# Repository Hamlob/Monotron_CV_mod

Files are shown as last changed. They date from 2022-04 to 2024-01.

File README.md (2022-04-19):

# Monotron_CV_mod
A modification for Korg's Monotron Delay, which makes it accept standard Eurorack CV voltages (Pitch, Gate and Cutoff CV). The mod also provides an option to power the monotron via micro-USB.
<br />
<br />
Input specs:<br />
Pitch CV: 1V/oct (0-10V) <br />
Gate CV: GATE ON-> 5-12V <br />
Cutoff CV: 0-10Vpp (possibly more if you attenuate the signal using the Cutoff Trimmer, but it can damage the op-amp if the trimmer is in the wrong position).
<br />
<br />
Micro-usb: 5 +/- 10%

Output:<br />
Connect GATE, VCC, GND, CUTOFF and LFO testpads of Monotron to GATE, +5V, GND, CUTOFF and LFO pins of the mod PCB respectively, by soldering wires between them.<br />
GATE and CUTOFF are output signals being provided by the mod PCB. LFO is an input signal generated on the monotron board and routed into the mod PCB, which includes a proper output jack.
<br />
<br />
If you wish to use USB power, you need to cut the track as shown on Figure 1 to disconnect the batteries from Vcc. Then you need to solder a wire from the positive lead of the capacitor to the Bat pin of the mod PCB (Figure 2). This is done to prevent current flowing from USB to the batteries, potentionally damaging them (Figure 3).
<br />
<br />
Figure 1: <br />
ReadmeFigure1
<br />
<br />
Figure 2: <br />

<br />
Figure 3: <br />
ReadMeGithub

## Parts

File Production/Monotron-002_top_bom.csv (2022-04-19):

Comment | Designator | Footprint | LCSC Part #
1n | C1 | C0603
1u | C4 C8 | C0603
3k3 | R6 | R0603
6k8 | R10 | R0603
10k | R11 R21 | R0603
10n | C2 | C0603
10u | C5 | C0805
33k | R5 R9 | R0603
47k | R1 R2 R3 R4 R13 R14 R15 R16 R17 | R0603
47u | C9 C10 C11 C12 | C0805
68k | R18 R19 | R0603
100k | R7 | R0603
100n | C3 | C0603
220n | C6 C7 | C0603
LM324D | IC1 | SO14
MICRO-USB-RECEPTACLE47589-0001 | X1 | 47589-0001
N-MOSFET | Q1 | SOT23-3
TPB1 27 | TP1 | B1 27
TPB1 27 | TP2 | B1 27
TPB1 27 | TP3 | B1 27
TPB1 27 | TP4 | B1 27
TPB1 27 | TP5 | B1 27
TPB1 27 | TP6 | B1 27
TPB1 27 | TP7 | B1 27
TPB1 27 | TP8 | B1 27
TPB1 27 | TP9 | B1 27
TPS2105D | U1 | D8

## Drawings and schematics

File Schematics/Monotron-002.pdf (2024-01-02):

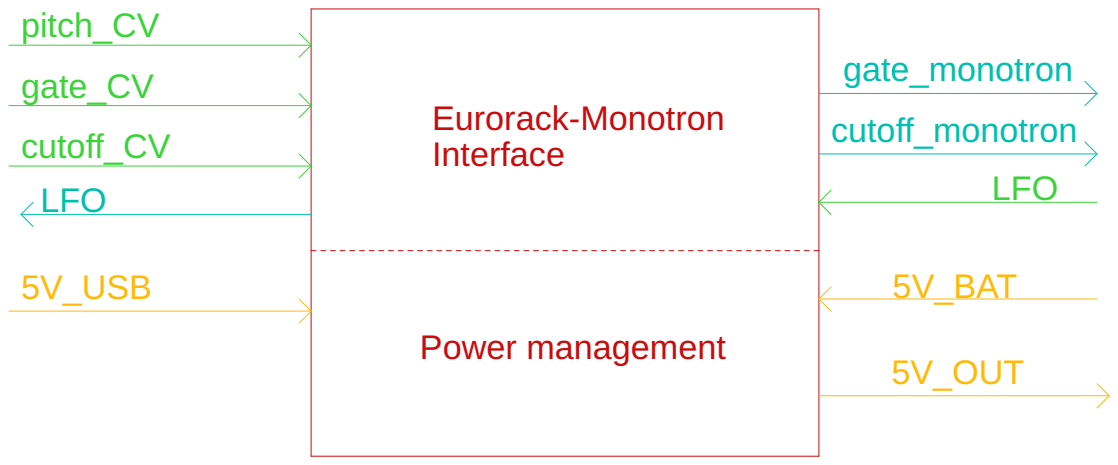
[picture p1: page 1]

WITHOUT PRIOR WRITTEN PERMISSION OF MAGE CONTROL SYSTEMS LTD. Title: Mage Control Systems Ltd. 45 Rankine Avenue East Kilbride F75 0QF

THIS DOCUMENT CONTAINS INFORMATION PROPRIETARY TO MAGE CONTROL SYSTEMS LTD. AND SHALL NOT BE REPRODUCED OR TRANSFERRED TO OTHER DOCUMENTS OR DISCLOSED

TO OTHER PARTIES OR USED FOR ANY PURPOSES OTHER THAT FOR WHICH IT IS FURNISHED

Name Peter Konecny | Initials PK | Date Drawn Chkd 13/04/2022

Interface between eurorack CV and Monotron

Document No: | Rev: CV_MONOTRON-002 2 | Sheet 1/3 of

Approved

02/01/2024 19:42 C:\Users\Admin\Documents\EAGLE\projects\Monotron\Monotron-002.sch (Sheet: 1/3)

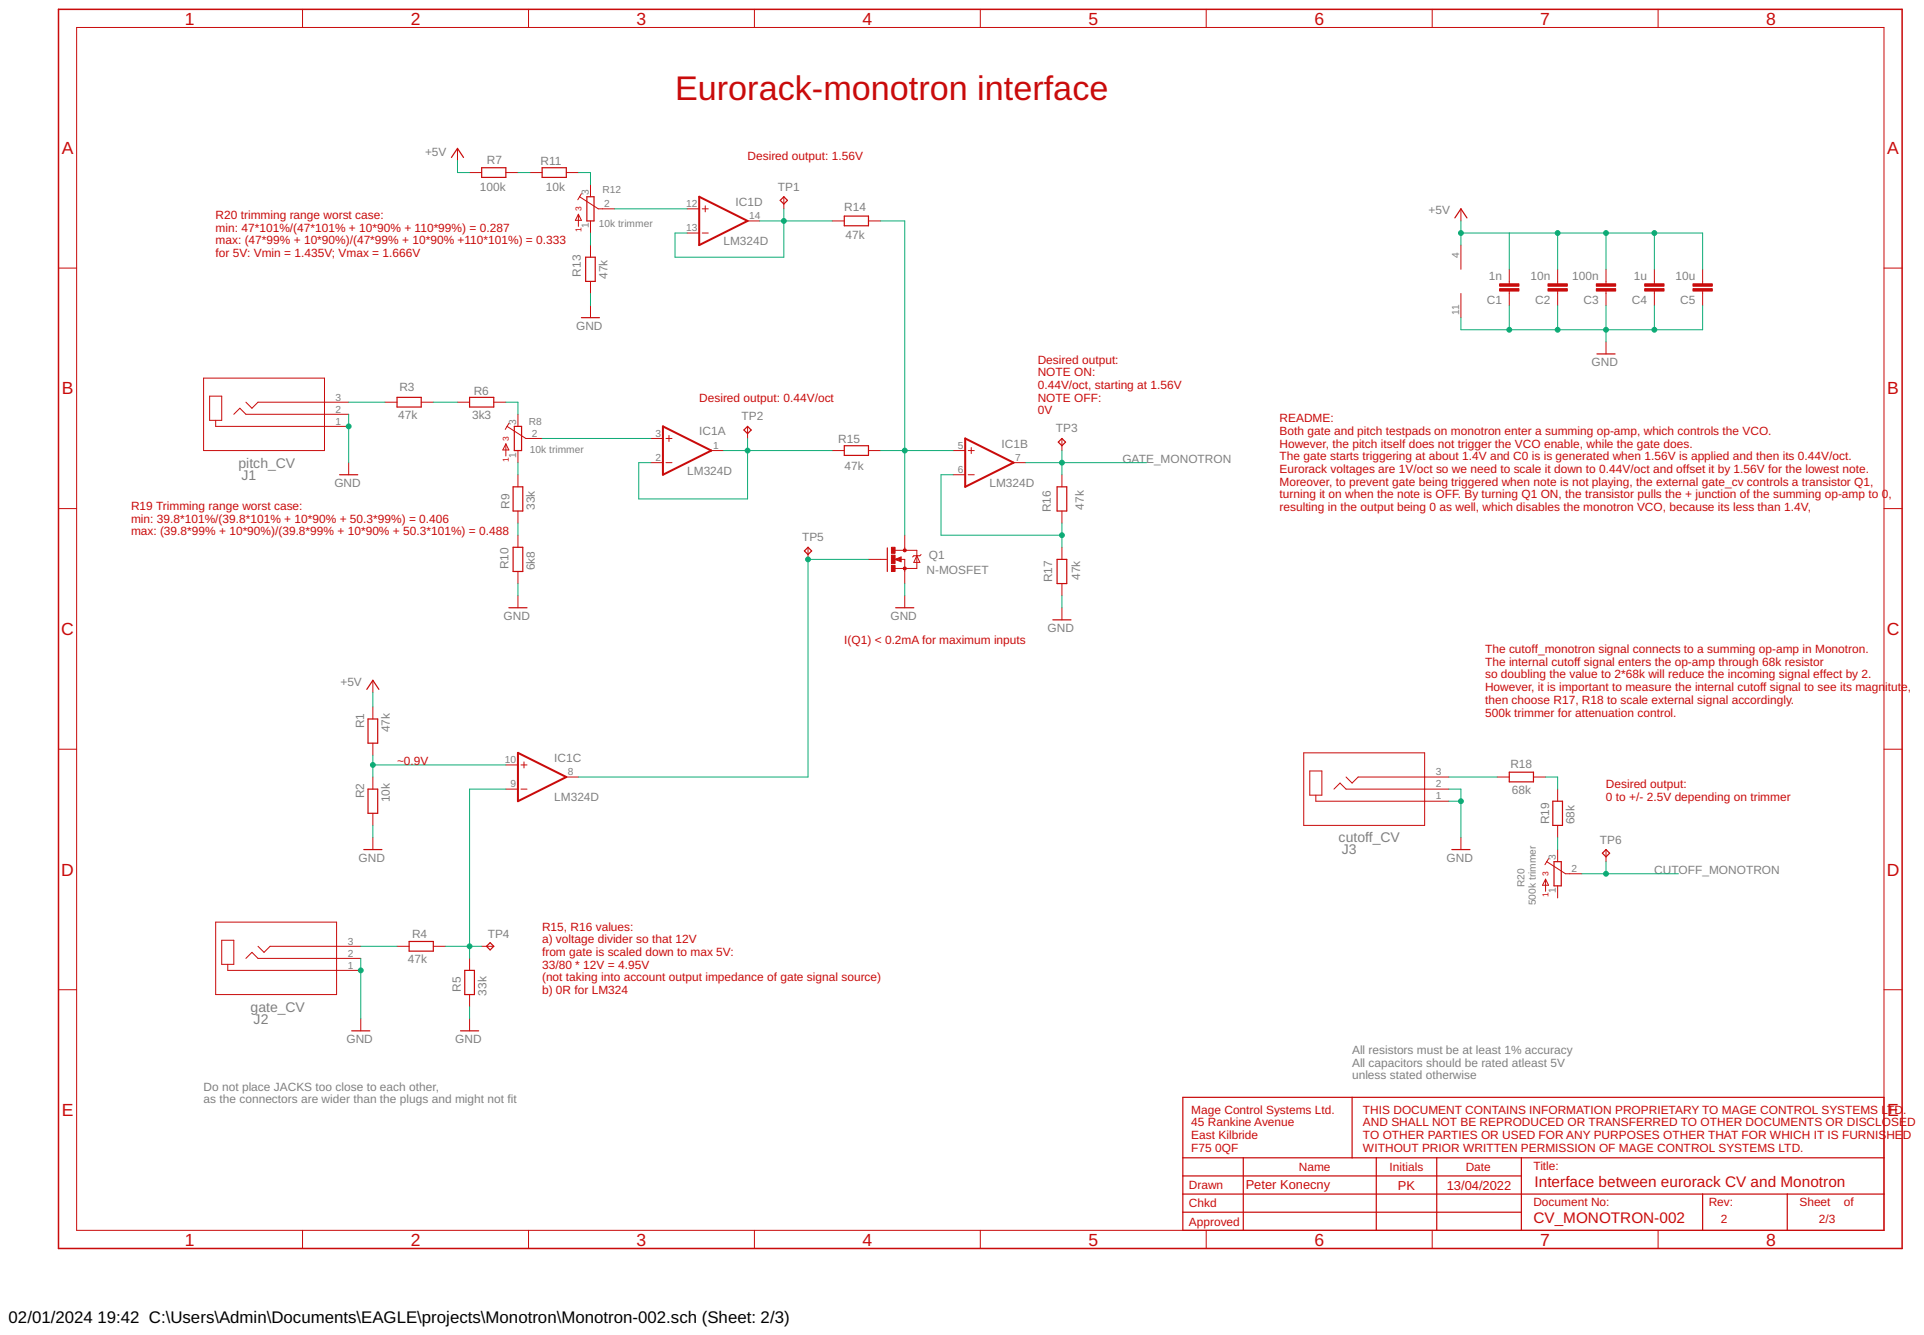
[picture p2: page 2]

R20 trimming range worst case: min: 47*101%/(47*101% + 10*90% + 110*99%) = 0.287 max: (47*99% + 10*90%)/(47*99% + 10*90% +110*101%) = 0.333

Desired output: NOTE ON: 0.44V/oct, starting at 1.56V

README: Both gate and pitch testpads on monotron enter a summing op-amp, which controls the VCO. However, the pitch itself does not trigger the VCO enable, while the gate does. The gate starts triggering at about 1.4V and C0 is is generated when 1.56V is applied and then its 0.44V/oct. Eurorack voltages are 1V/oct so we need to scale it down to 0.44V/oct and offset it by 1.56V for the lowest note. Moreover, to prevent gate being triggered when note is not playing, the external gate_cv controls a transistor Q1,

The cutoff_monotron signal connects to a summing op-amp in Monotron. The internal cutoff signal enters the op-amp through 68k resistor so doubling the value to 2*68k will reduce the incoming signal effect by 2. However, it is important to measure the internal cutoff signal to see its magnitute,

then choose R17, R18 to scale external signal accordingly. 500k trimmer for attenuation control.

Desired output: 0 to +/- 2.5V depending on trimmer

R15, R16 values: a) voltage divider so that 12V

from gate is scaled down to max 5V: 33/80 * 12V = 4.95V

(not taking into account output impedance of gate signal source)
b) 0R for LM324

All resistors must be at least 1% accuracy
All capacitors should be rated atleast 5V

unless stated otherwise Do not place JACKS too close to each other, as the connectors are wider than the plugs and might not fit

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

TO OTHER PARTIES OR USED FOR ANY PURPOSES OTHER THAT FOR WHICH IT IS FURNISHED

Name Peter Konecny | Initials PK | Date Drawn Chkd 13/04/2022

Interface between eurorack CV and Monotron

Document No: | Rev: CV_MONOTRON-002 2 | Sheet 2/3 of

Approved

02/01/2024 19:42 C:\Users\Admin\Documents\EAGLE\projects\Monotron\Monotron-002.sch (Sheet: 2/3)

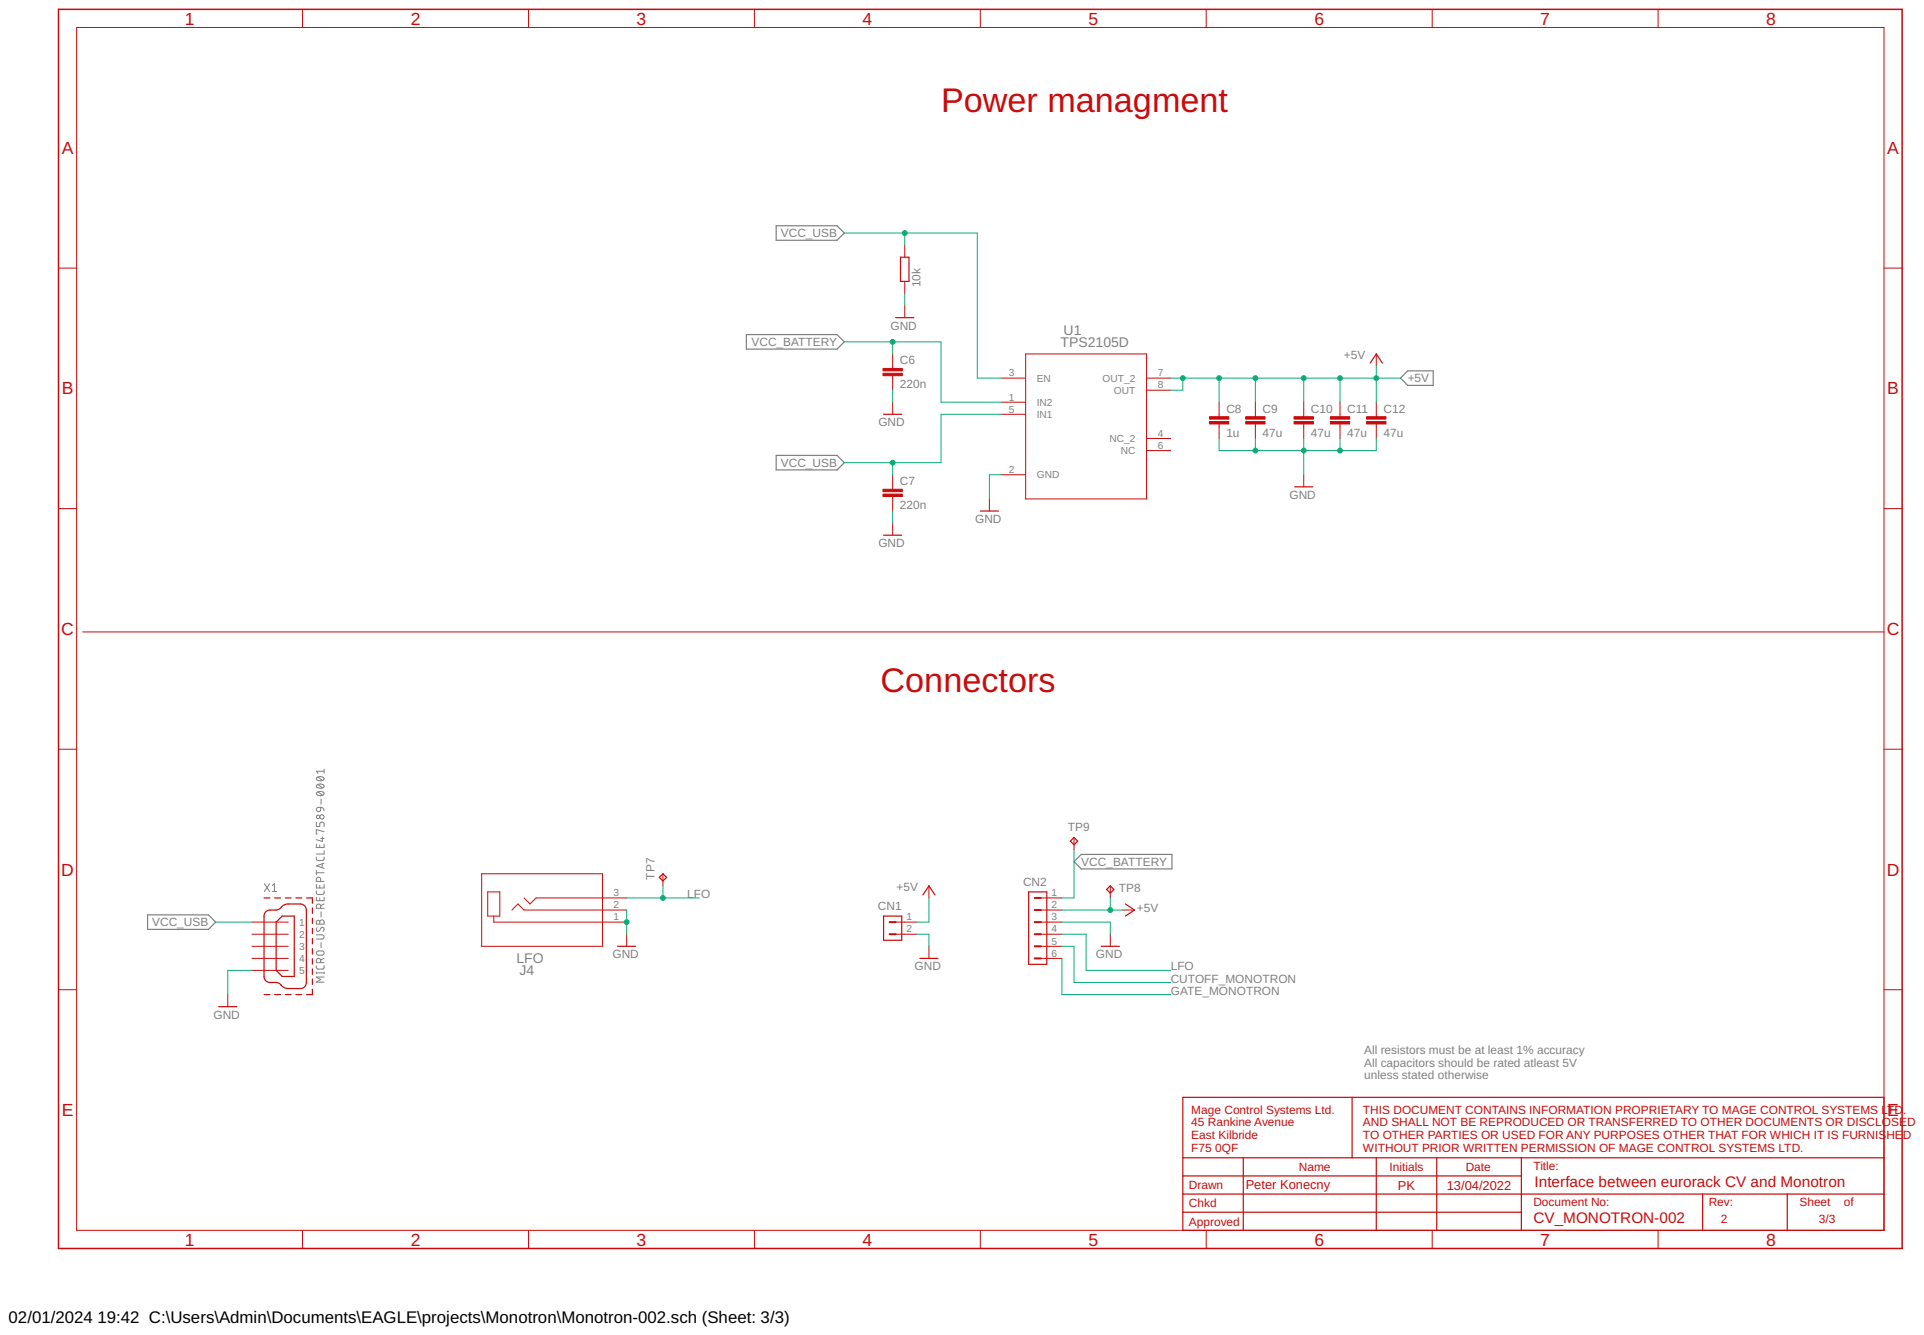
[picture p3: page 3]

All resistors must be at least 1% accuracy
All capacitors should be rated atleast 5V
unless stated otherwise

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

TO OTHER PARTIES OR USED FOR ANY PURPOSES OTHER THAT FOR WHICH IT IS FURNISHED

Name Peter Konecny | Initials PK | Date Drawn Chkd 13/04/2022

Interface between eurorack CV and Monotron

Document No: | Rev: CV_MONOTRON-002 2 | Sheet 3/3 of

Approved

02/01/2024 19:42 C:\Users\Admin\Documents\EAGLE\projects\Monotron\Monotron-002.sch (Sheet: 3/3)

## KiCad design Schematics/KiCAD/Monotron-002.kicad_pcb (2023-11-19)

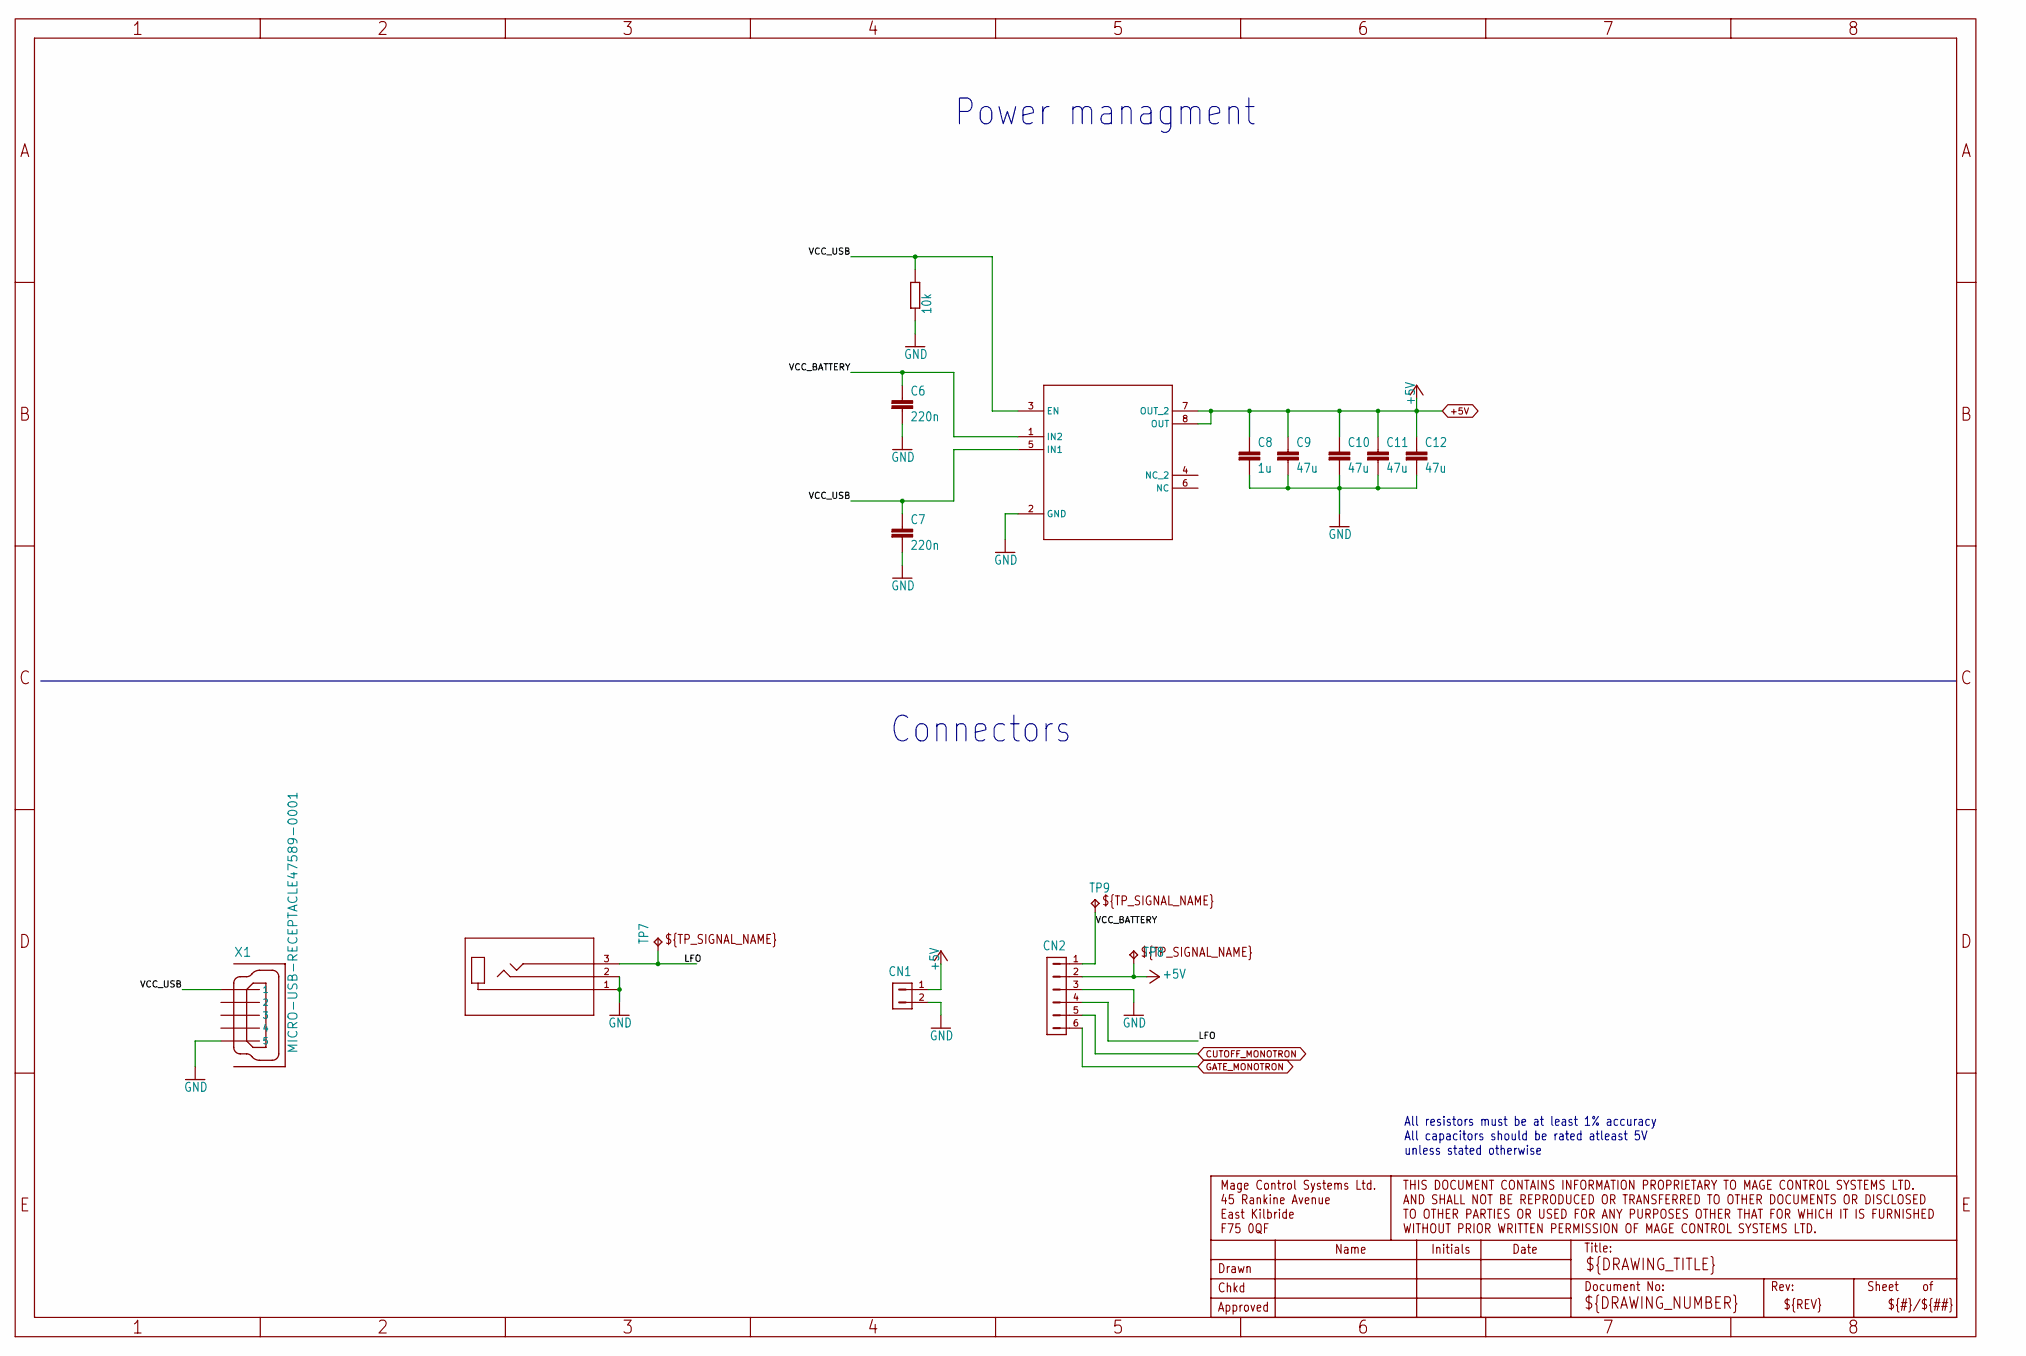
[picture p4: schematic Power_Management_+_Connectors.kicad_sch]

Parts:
C6, C7: 220n; C0603
C8: 1u; C0603
C9, C10, C11, C12: 47u; C0805
CN1: HDR-1X2-SIP-100; SIP-100-2V
CN2: HDR-1X6-SIP-100; SIP-100-6V
J4: STX-3000; STX-3000_KYC
R21: 10k; R0603
TP7, TP8, TP9: TPB1,27; B1,27
U1: TPS2105D; D8
X1: MICRO-USB-RECEPTACLE47589-0001; 47589-0001

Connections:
+5V: C8.1, C9.1, C10.1, C11.1, C12.1, CN1.1, CN2.2, TP8.TP, U1.7 (OUT_2), U1.8 (OUT); also elsewhere on the board
CUTOFF_MONOTRON: CN2.5; also elsewhere on the board
GATE_MONOTRON: CN2.6; also elsewhere on the board
GND: C6.2, C7.2, C8.2, C9.2, C10.2, C11.2, C12.2, CN1.2, CN2.3, J4.1, J4.2, R21.1, U1.2 (GND), X1.5; also elsewhere on the board
LFO: CN2.4, J4.3, TP7.TP
VCC_BATTERY: C6.1, CN2.1, TP9.TP, U1.1 (IN2)
VCC_USB: C7.1, R21.2, U1.3 (EN), U1.5 (IN1), X1.1

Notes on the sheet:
Power managment
Connectors
All resistors must be at least 1% accuracy All capacitors should be rated atleast 5V unless stated otherwise

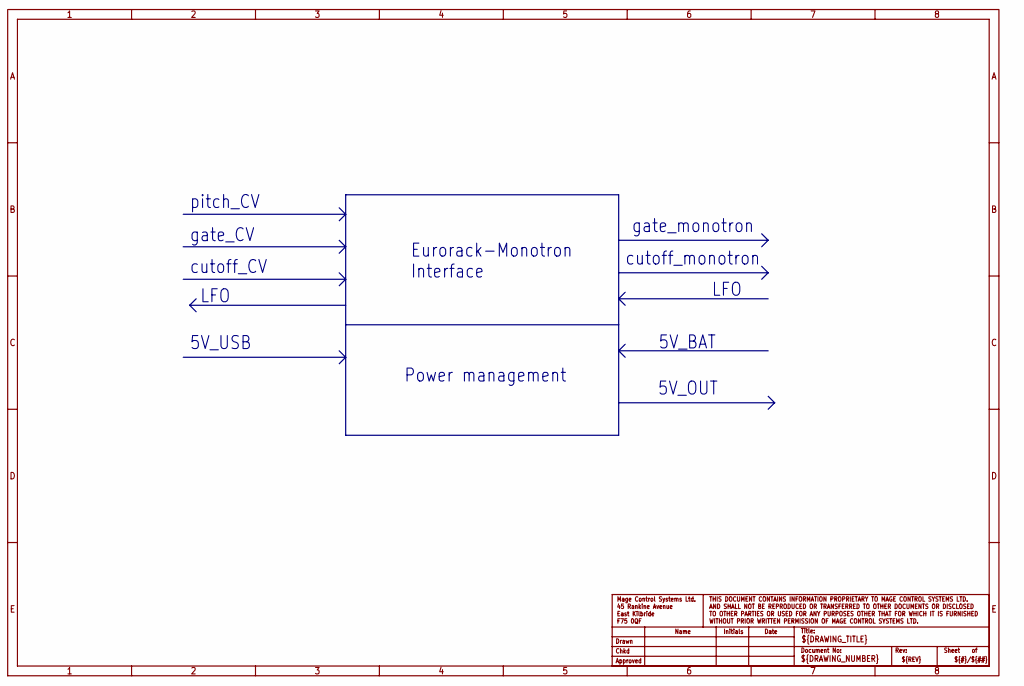
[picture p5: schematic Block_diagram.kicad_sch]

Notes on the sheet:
Power management
5V_USB
Eurorack-Monotron Interface
gate_CV
gate_monotron
LFO
pitch_CV
5V_OUT
cutoff_CV
cutoff_monotron
5V_BAT

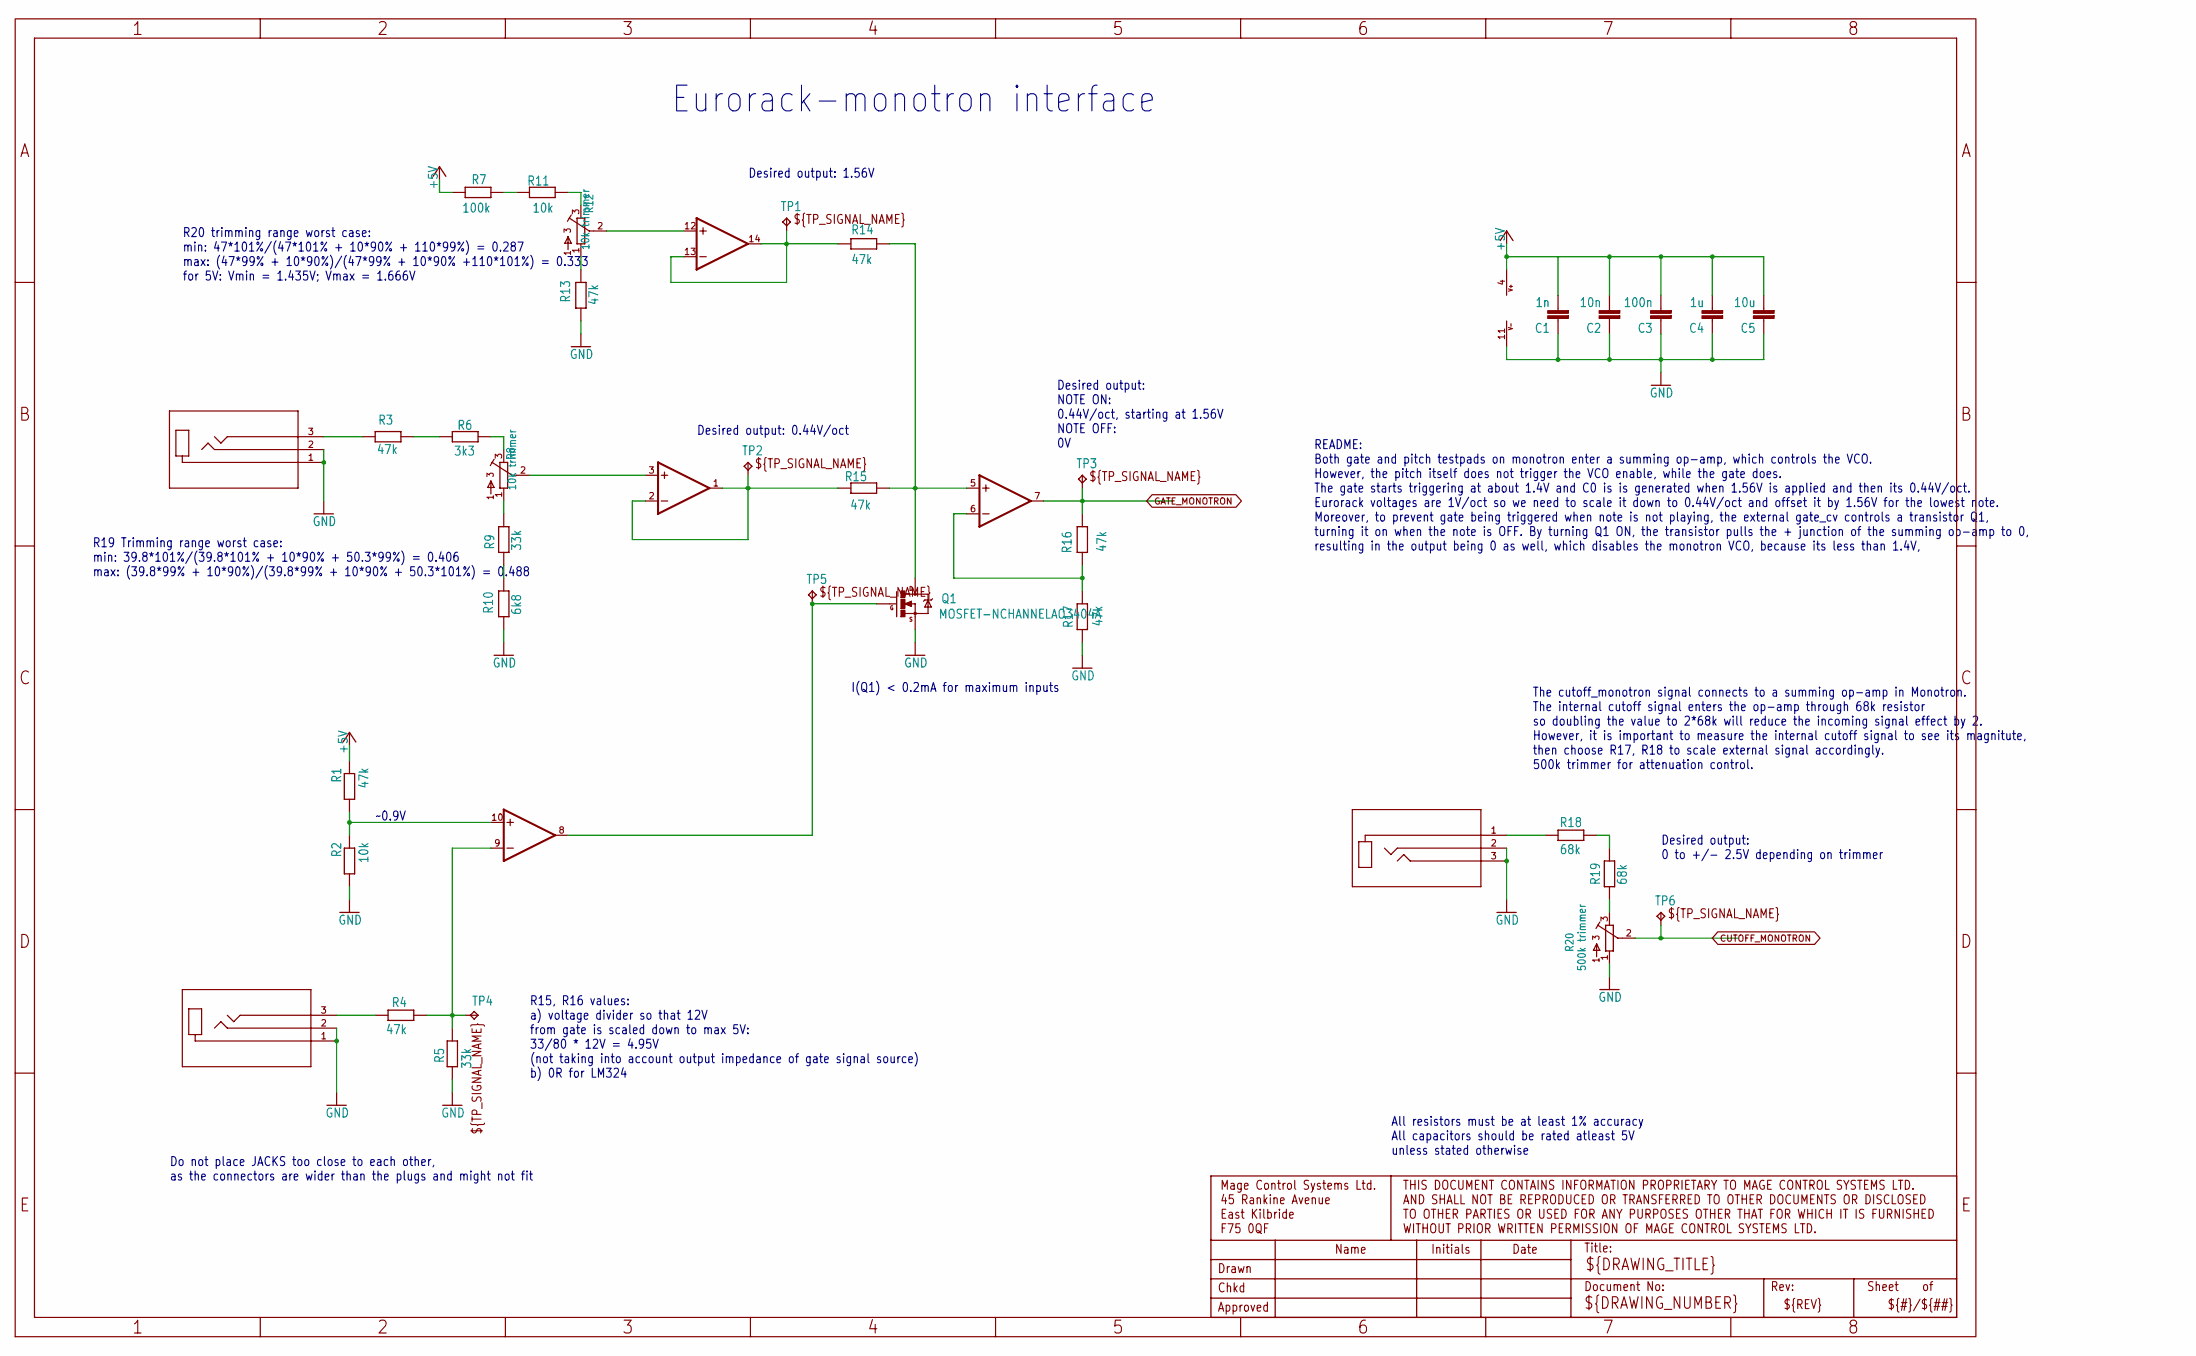
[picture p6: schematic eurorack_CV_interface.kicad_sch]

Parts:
C1: 1n; C0603
C2: 10n; C0603
C3: 100n; C0603
C4: 1u; C0603
C5: 10u; C0805
IC1: LM324D; SO14
J1, J2, J3: STX-3000; STX-3000_KYC
Q1: MOSFET-NCHANNELAO3404A; SOT23-3
R1, R3, R4, R13, R14, R15, R16, R17: 47k; R0603
R2, R11: 10k; R0603
R5, R9: 33k; R0603
R6: 3k3; R0603
R7: 100k; R0603
R8, R12: 10k trimmer; 3362R
R10: 6k8; R0603
R18, R19: 68k; R0603
R20: 500k trimmer; 3362R
TP1, TP2, TP3, TP4, TP5, TP6: TPB1,27; B1,27

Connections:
+5V: C1.2, C2.2, C3.2, C4.2, C5.2, IC1.4 (V+), R1.1, R7.2; also elsewhere on the board
CUTOFF_MONOTRON: R20.2, TP6.TP; also elsewhere on the board
GATE_MONOTRON: IC1.7 (OUT), R16.1, TP3.TP; also elsewhere on the board
GND: C1.1, C2.1, C3.1, C4.1, C5.1, IC1.11 (V-), J1.1, J1.2, J2.1, J2.2, J3.2, J3.3, Q1.2 (S), R2.2, R5.2, R10.1, R13.1, R17.2, R20.1; also elsewhere on the board
unnamed: R3.2, R6.2
unnamed: R9.1, R10.2
unnamed: IC1.1 (OUT), IC1.2 (-IN), R15.2, TP2.TP
unnamed: J1.3, R3.1
unnamed: IC1.5 (+IN), Q1.3 (D), R14.1, R15.1
unnamed: IC1.12 (+IN), R12.2
unnamed: J3.1, R18.2
unnamed: R18.1, R19.2
unnamed: R19.1, R20.3
unnamed: R8.1, R9.2
unnamed: IC1.8 (OUT), Q1.1 (G), TP5.TP
unnamed: R6.1, R8.3
unnamed: IC1.3 (+IN), R8.2
unnamed: R12.1, R13.2
unnamed: R11.1, R12.3
unnamed: R7.1, R11.2
unnamed: J2.3, R4.2
unnamed: IC1.9 (-IN), R4.1, R5.1, TP4.TP
unnamed: IC1.10 (+IN), R1.2, R2.1
unnamed: IC1.13 (-IN), IC1.14 (OUT), R14.2, TP1.TP
unnamed: IC1.6 (-IN), R16.2, R17.1

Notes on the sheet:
Desired output: 1.56V
R15, R16 values: a) voltage divider so that 12V from gate is scaled down to max 5V: 33/80 * 12V = 4.95V (not taking into account output impedance of gate signal source) b) 0R for LM324
All resistors must be at least 1% accuracy All capacitors should be rated atleast 5V unless stated otherwise
R20 trimming range worst case: min: 47*101%/(47*101% + 10*90% + 110*99%) = 0.287 max: (47*99% + 10*90%)/(47*99% + 10*90% +110*101%) = 0.333 for 5V: Vmin = 1.435V; Vmax = 1.666V
The cutoff_monotron signal connects to a summing op-amp in Monotron. The internal cutoff signal enters the op-amp through 68k resistor so doubling the value to 2*68k will reduce the incoming signal effect by 2. However, it is important to measure the internal cutoff signal to see its magnitute, the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
I(Q1) < 0.2mA for maximum inputs
README: Both gate and pitch testpads on monotron enter a summing op-amp, which controls the VCO. However, the pitch itself does not trigger the VCO enable, while the gate does. The gate starts triggering at about 1.4V and C0 is is generated when 1.56V is applied and then its 0.44V/oct. Eurorack vol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
Desired output: 0 to +/- 2.5V depending on trimmer
Desired output: 0.44V/oct
Eurorack-monotron interface
~0.9V
Do not place JACKS too close to each other, as the connectors are wider than the plugs and might not fit
Desired output: NOTE ON: 0.44V/oct, starting at 1.56V NOTE OFF: 0V
R19 Trimming range worst case: min: 39.8*101%/(39.8*101% + 10*90% + 50.3*99%) = 0.406 max: (39.8*99% + 10*90%)/(39.8*99% + 10*90% + 50.3*101%) = 0.488

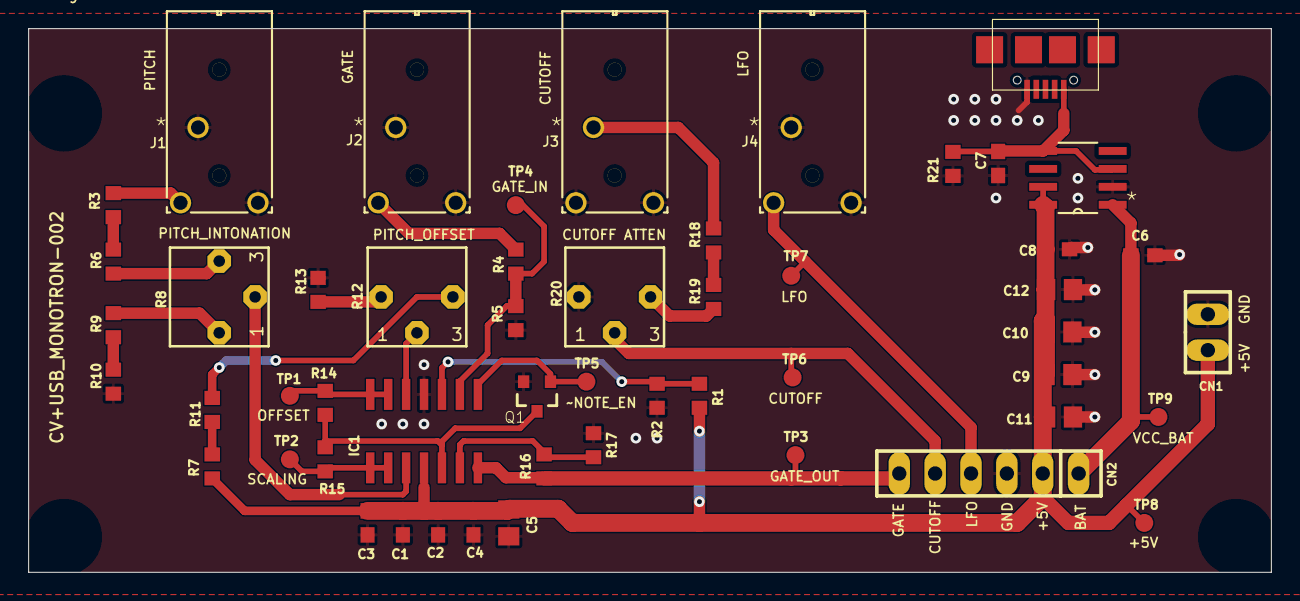
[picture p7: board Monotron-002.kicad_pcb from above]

Board: 2 copper layers, 88.0 x 38.5 mm, 52 parts (0 on the bottom side), 28 nets.

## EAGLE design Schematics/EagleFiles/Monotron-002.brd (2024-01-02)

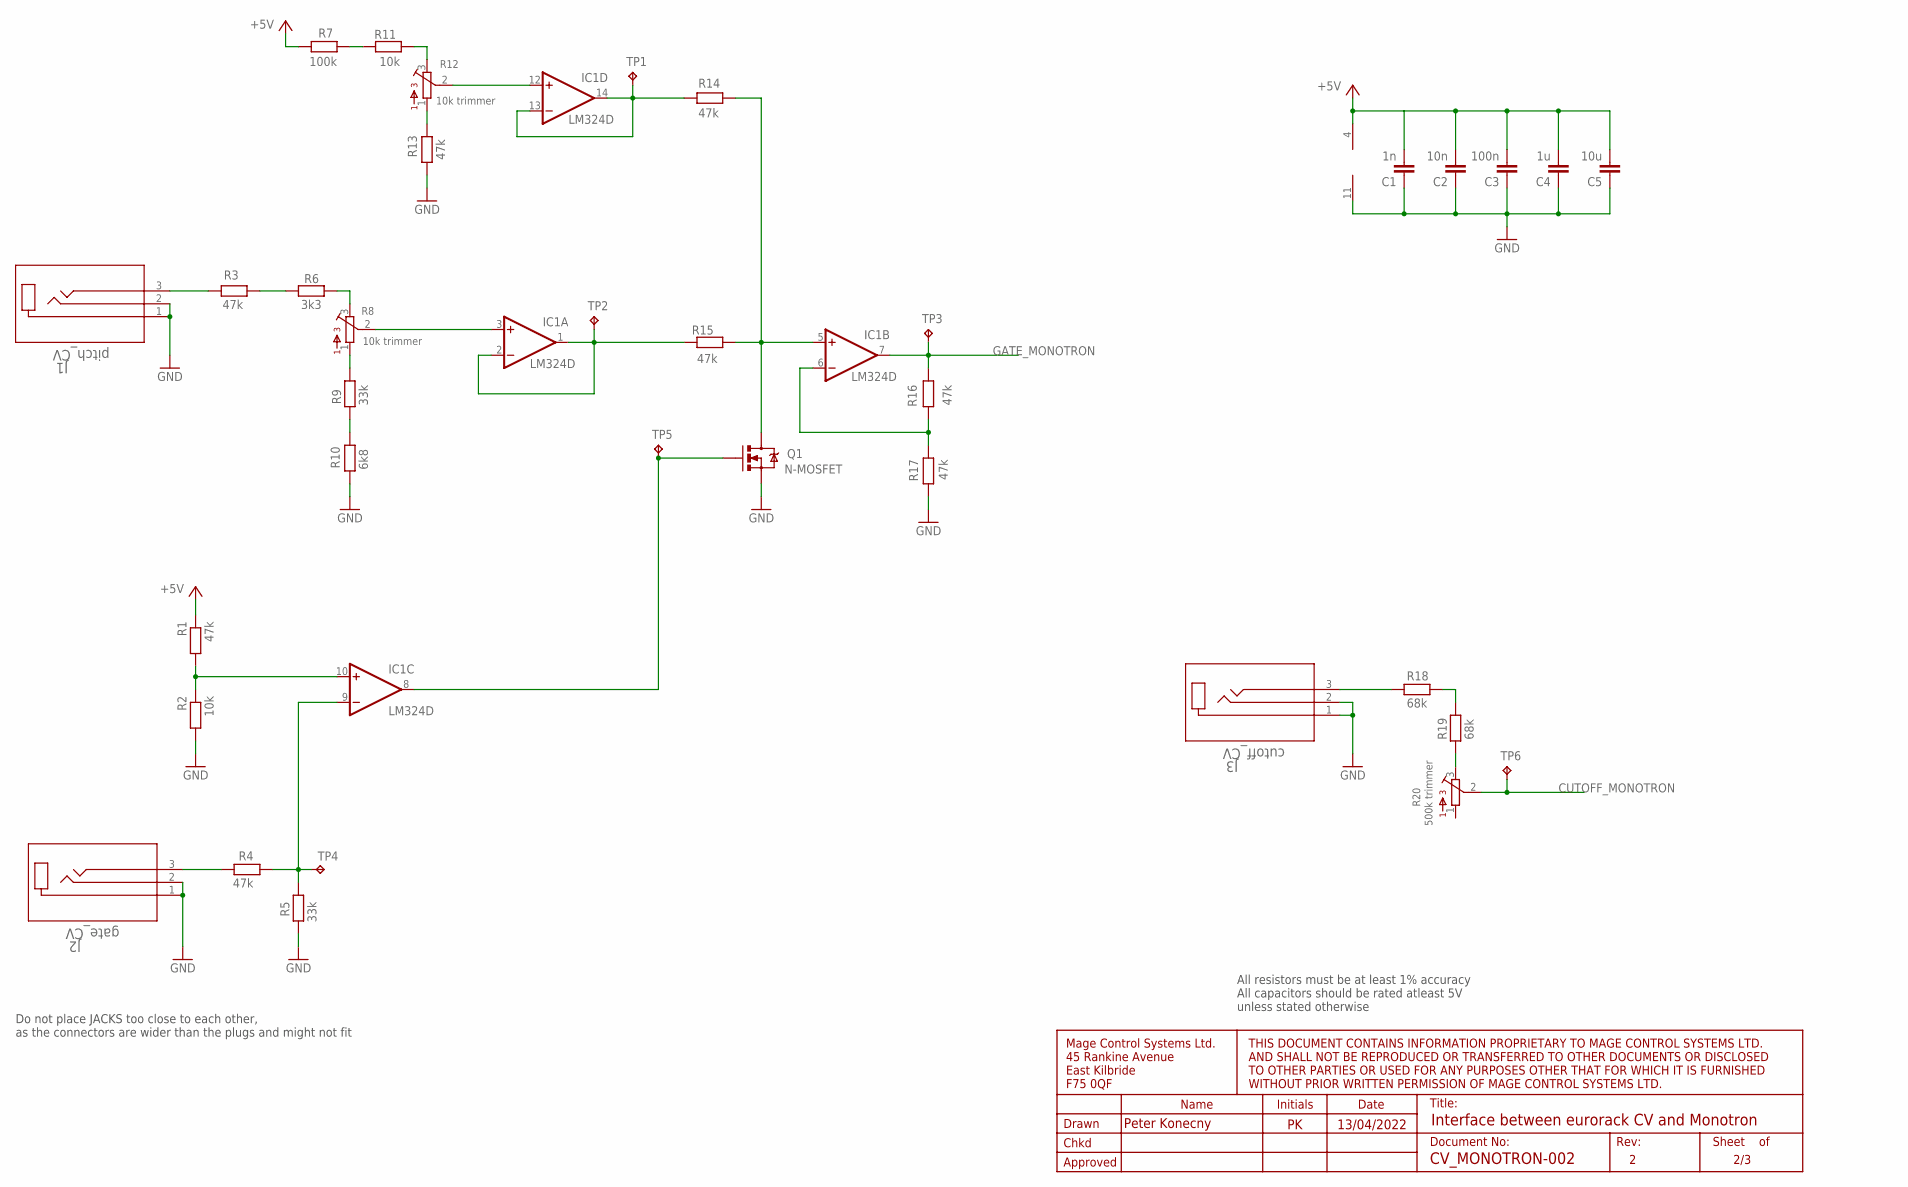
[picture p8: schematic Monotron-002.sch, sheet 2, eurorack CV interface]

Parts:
C1: 1n; C0603
C2: 10n; C0603
C3: 100n; C0603
C4: 1u; C0603
C5: 10u; C0805
IC1: LM324D; SO14
J1: pitch_CV; STX-3000_KYC
J2: gate_CV; STX-3000_KYC
J3: cutoff_CV; STX-3000_KYC
Q1: N-MOSFET; SOT23-3
R1, R3, R4, R13, R14, R15, R16, R17: 47k; R0603
R2, R11: 10k; R0603
R5, R9: 33k; R0603
R6: 3k3; R0603
R7: 100k; R0603
R8, R12: 10k trimmer; 3362R
R10: 6k8; R0603
R18, R19: 68k; R0603
R20: 500k trimmer; 3362R
TP1, TP2, TP3, TP4, TP5, TP6: TPB1,27; B1,27

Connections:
+5V: C1.2, C2.2, C3.2, C4.2, C5.2, IC1.4 (V+), R1.1, R7.2; also elsewhere on the board
CUTOFF_MONOTRON: R20.2, TP6.TP; also elsewhere on the board
GATE_MONOTRON: IC1.7 (OUT), R16.1, TP3.TP; also elsewhere on the board
GND: C1.1, C2.1, C3.1, C4.1, C5.1, IC1.11 (V-), J1.1, J1.2, J2.1, J2.2, J3.1, J3.2, Q1.2 (S), R2.2, R5.2, R10.1, R13.1, R17.2; also elsewhere on the board
unnamed: R3.2, R6.2
unnamed: R9.1, R10.2
unnamed: IC1.1 (OUT), IC1.2 (-IN), R15.2, TP2.TP
unnamed: J1.3, R3.1
unnamed: IC1.5 (+IN), Q1.3 (D), R14.1, R15.1
unnamed: J3.3, R18.2
unnamed: IC1.12 (+IN), R12.2
unnamed: R18.1, R19.2
unnamed: R19.1, R20.3
unnamed: R8.1, R9.2
unnamed: IC1.8 (OUT), Q1.1 (G), TP5.TP
unnamed: R6.1, R8.3
unnamed: IC1.3 (+IN), R8.2
unnamed: R12.1, R13.2
unnamed: R11.1, R12.3
unnamed: R7.1, R11.2
unnamed: J2.3, R4.2
unnamed: IC1.9 (-IN), R4.1, R5.1, TP4.TP
unnamed: IC1.10 (+IN), R1.2, R2.1
unnamed: IC1.13 (-IN), IC1.14 (OUT), R14.2, TP1.TP
unnamed: IC1.6 (-IN), R16.2, R17.1

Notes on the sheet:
All resistors must be at least 1% accuracy All capacitors should be rated atleast 5V unless stated otherwise
Do not place JACKS too close to each other, as the connectors are wider than the plugs and might not fit

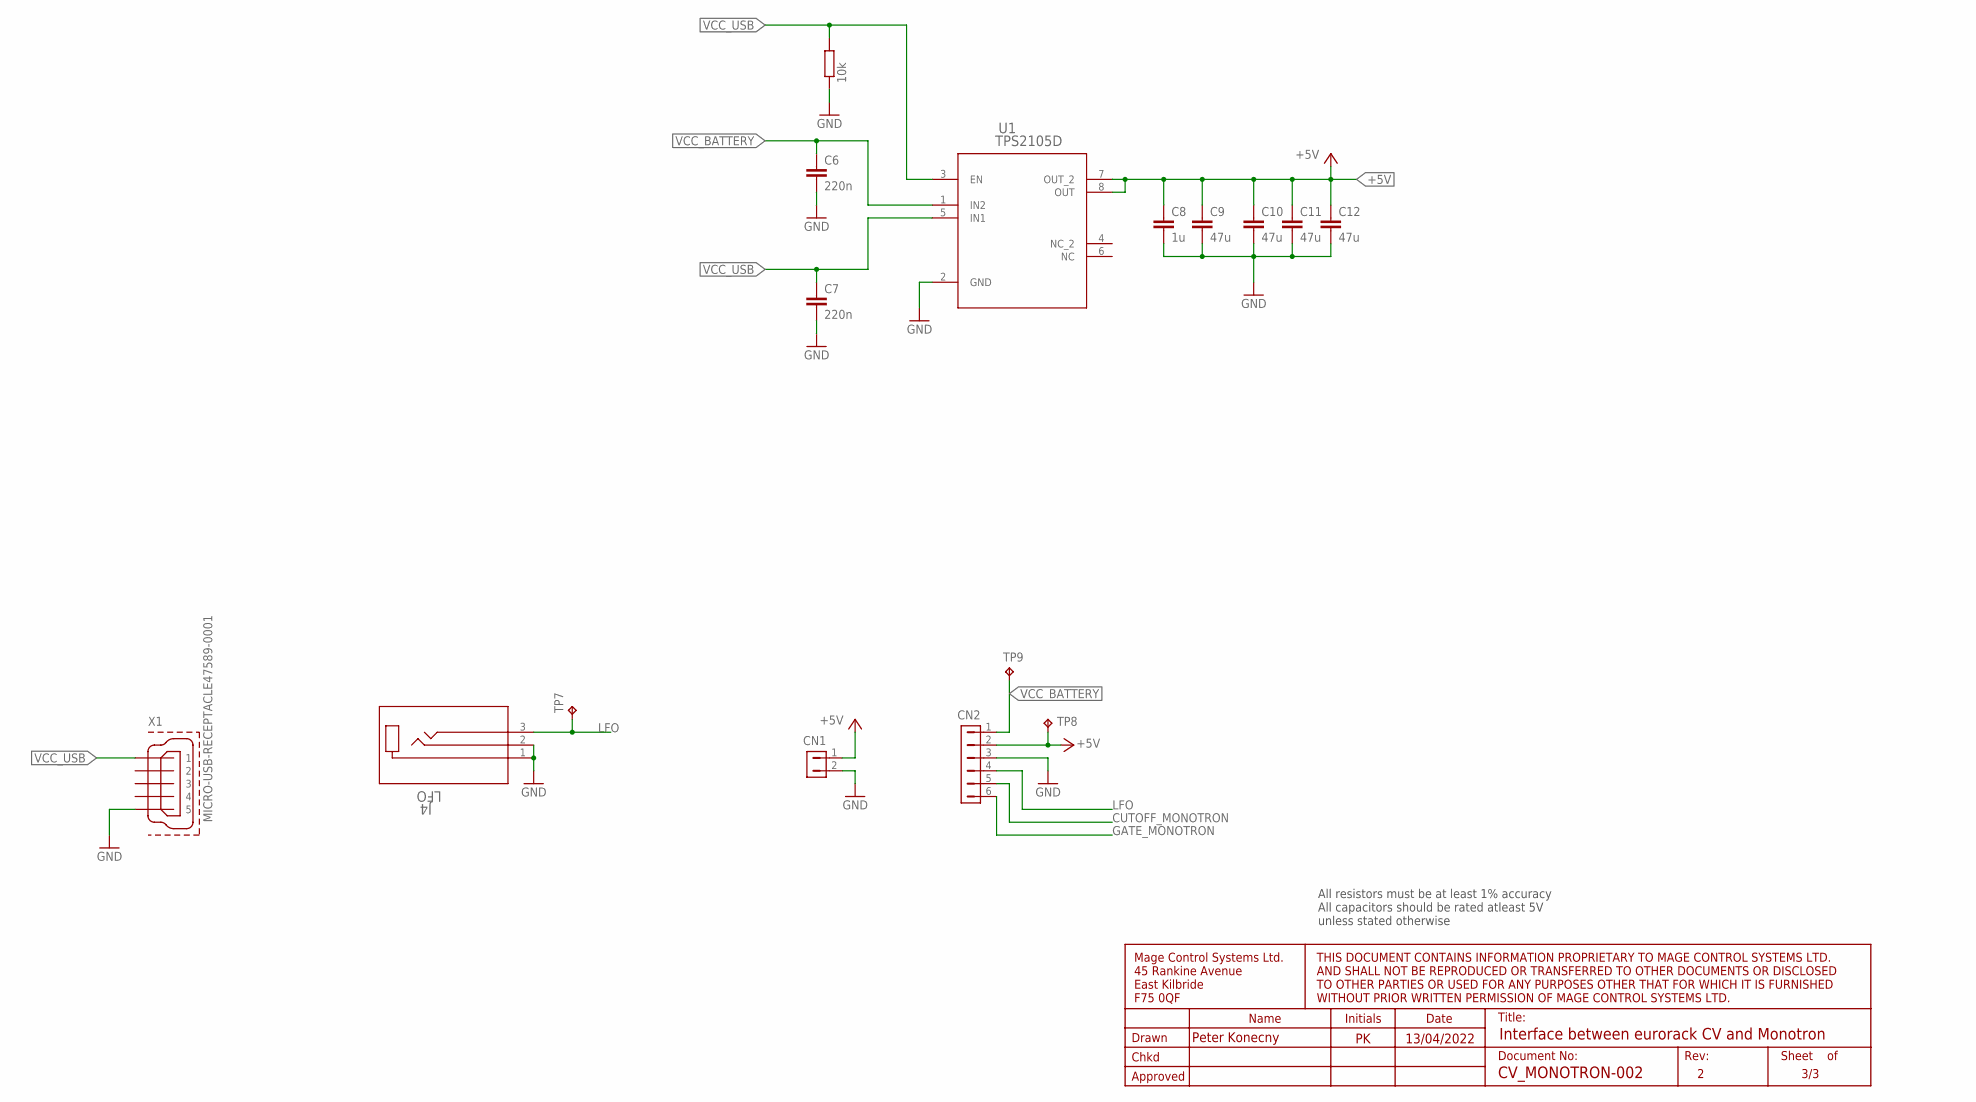
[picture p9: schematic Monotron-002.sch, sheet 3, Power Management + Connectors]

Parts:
C6, C7: 220n; C0603
C8: 1u; C0603
C9, C10, C11, C12: 47u; C0805
CN1: HDR-1X2-SIP-100; SIP-100-2V
CN2: HDR-1X6-SIP-100; SIP-100-6V
J4: LFO; STX-3000_KYC
R21: 10k; R0603
TP7, TP8, TP9: TPB1,27; B1,27
U1: TPS2105D; D8
X1: MICRO-USB-RECEPTACLE47589-0001; 47589-0001

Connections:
+5V: C8.1, C9.1, C10.1, C11.1, C12.1, CN1.1, CN2.2, TP8.TP, U1.7 (OUT_2), U1.8 (OUT); also elsewhere on the board
CUTOFF_MONOTRON: CN2.5; also elsewhere on the board
GATE_MONOTRON: CN2.6; also elsewhere on the board
GND: C6.2, C7.2, C8.2, C9.2, C10.2, C11.2, C12.2, CN1.2, CN2.3, J4.1, J4.2, R21.1, U1.2 (GND), X1.5; also elsewhere on the board
LFO: CN2.4, J4.3, TP7.TP
VCC_BATTERY: C6.1, CN2.1, TP9.TP, U1.1 (IN2)
VCC_USB: C7.1, R21.2, U1.3 (EN), U1.5 (IN1), X1.1

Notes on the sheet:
All resistors must be at least 1% accuracy All capacitors should be rated atleast 5V unless stated otherwise

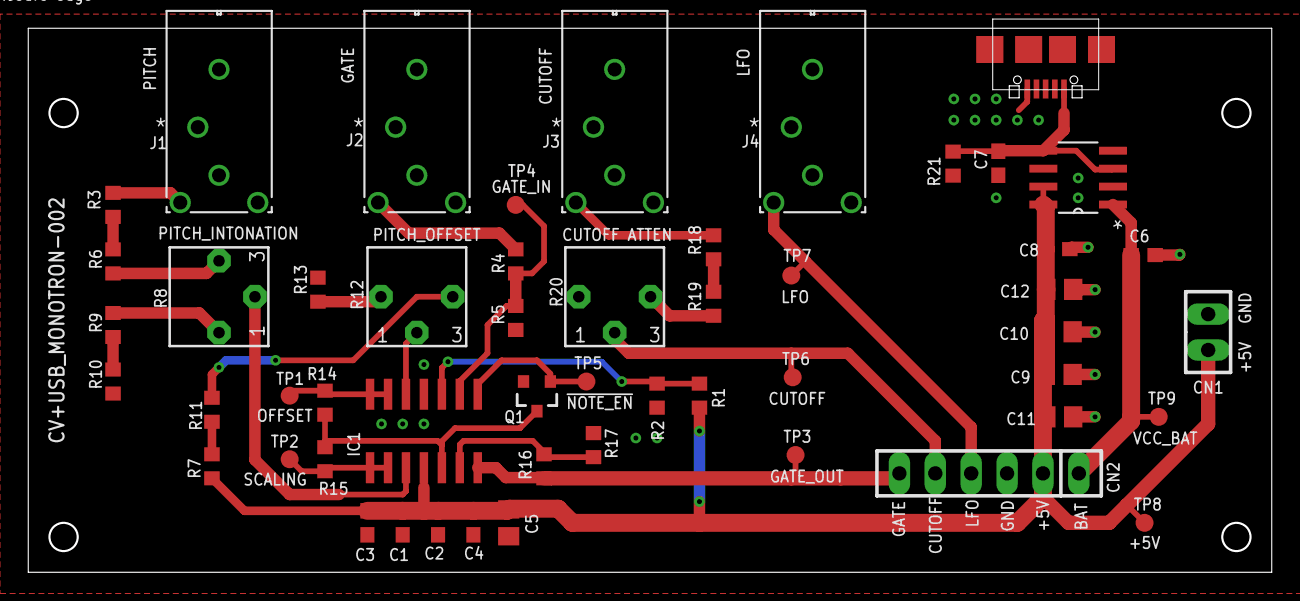
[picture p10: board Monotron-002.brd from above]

Board: 2 copper layers, 88.0 x 38.5 mm, 52 parts (0 on the bottom side), 28 nets.

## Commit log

2022-04-19 Add files via upload
    Bom, CPL, datasheet folder and gerbers
    [Monotron-002_top_bom.csv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]
2022-04-19 Add files via upload
    Eagle files
    [Monotron-002.brd, Monotron-002.sch]
2023-10-29 updated schematics and brd files
    [Monotron-002.brd, Monotron-002.sch]
2023-11-19 added kicad files
    [Block_diagram.kicad_sch, Monotron-002.kicad_pcb, Monotron-002.kicad_sch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]
2024-01-02 updated schematic
    corrected cutoff connector wiring and cutoff trimmer disconnected from GND
2024-01-02 updated eagle files
    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
    [Monotron-002.brd, Monotron-002.sch]
2024-01-02 updated gerbers
    gerbers with corrected cutoff connector and cutoff trimmer

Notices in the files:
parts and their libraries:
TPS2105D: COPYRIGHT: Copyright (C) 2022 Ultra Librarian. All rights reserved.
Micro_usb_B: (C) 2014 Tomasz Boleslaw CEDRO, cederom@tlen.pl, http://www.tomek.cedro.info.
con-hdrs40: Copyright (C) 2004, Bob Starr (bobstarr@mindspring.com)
